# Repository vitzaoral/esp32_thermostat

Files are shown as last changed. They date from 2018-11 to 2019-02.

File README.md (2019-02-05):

# ESP32 thermostat witch touch LCD

WiFi thermostat based on the ESP32 (Espressif WROOM-32 Developer Kit), using several SHT3X(SHT31-D) temperature/humidity sensor and ILI 9341 TFT LCD Touch display. Data are sent to the Blynk server. Thermostat can be controlled by the Blynk application from iPhone or directly by touch on the LCD. Project is free to use, coded in C++, created in Visual Code with [PlatfomIO IDE](http://docs.platformio.org/en/latest/ide/vscode.html).

> To build a project, you need to download all the necessary libraries and create the *settings.cpp* file in the src folder with specific settings:
```c++
// address 1 - enable/disable heating
#define EEPROM_ENABLED_DISABLED_HEATING_ADDRESS 1
// address 2 - target temperature
#define EEPROM_TARGET_HEATING_TEMPERATURE_ADDRESS 2
// address 3 - target temperature was set from display
#define EEPROM_TARGET_HEATING_TEMPERATURE_DISPLAY_SET_ADDRESS 3
// address 4 - heating enabled/disabled was set from display
#define EEPROM_ENABLED_DISABLED_HEATING_DISPLAY_SET_ADDRESS 4

#define MAX_TEMPERATURE_FROM_DISPLAY 25
#define MIN_TEMPERATURE_FROM_DISPLAY 10

// Thermostat project settings
struct Settings
{
    const char *ssid = "WIFI ssid";
    const char *password = "WIFI password";
    const char *blynkAuth = "blynkAuthDevice1";
    const char *blynkAuthOutdoor = "blynkAuthDevice2";
    const char *blynkAuthBedroom = "blynkAuthDevice3";
    const char *blynkAuthPantry = "blynkAuthDevice4";
    const char *hostNameOTA = "OTA host name";
    const char *passwordOTA = "OTA password";
    const char *version = "0.1.0";
};
```

### LCD Touch panel library & wiring:
I'm using awasome [TFT_eSPI](https://github.com/Bodmer/TFT_eSPI) library from Bodmer. You must update *User_Setup.h* file to set display type and pins. There is ESP32 section, my setup for this section is following:

```c++
// ###### EDIT THE PIN NUMBERS IN THE LINES FOLLOWING TO SUIT YOUR ESP32 SETUP   ######

// For ESP32 Dev board (only tested with ILI9341 display)
// The hardware SPI can be mapped to any pins
#define TFT_MISO 19
#define TFT_MOSI 23
#define TFT_SCLK 18
#define TFT_CS   15  // Chip select control pin
#define TFT_DC    2  // Data Command control pin
#define TFT_RST  -1  // Set TFT_RST to -1 if display RESET is connected to ESP32 board RST
#define TOUCH_CS  4  // Chip select pin (T_CS) of touch screen
```

For wires connection between the display and the ESP32 look to the schema..

### 5V relay vs 3.3V ESP32 pins
When you have 5V relay, there is a need to think about 3.3V ESP32 pins. You can't just connect ESP32 pin to source pin of the relay, it would not work. One way is insert MOSFET between ESP32 pin and source pin of the relay. Other solution is just use the 3.3V relay, or solid state relay. More information is [here](https://electronics.stackexchange.com/a/213058).

### Currents list:
* [ESP32](https://www.aliexpress.com/item/ESP-32-ESP-32S-Development-Board-WiFi-Bluetooth-Ultra-Low-Power-Consumption-Dual-Cores-ESP32-Board/32796032726.html) Espressif WROOM-32 Developer Kit
* [HLK-PM01](https://www.aliexpress.com/item/Free-Shippingn-HLK-PM01-AC-DC-220V-to-5V-mini-power-supply-module-intelligent-household-switch/32319515750.html) 220v to 5v power supply
* [Relay module shield](https://www.aliexpress.com/item/Free-Shipping-1PCS-5V-low-level-trigger-One-1-Channel-Relay-Module-interface-Board-Shield-For/32519570562.html)
* [2.8" SPI TFT LCD Touch Panel](https://www.aliexpress.com/item/1pcs-J34-F85-240x320-2-8-SPI-TFT-LCD-Touch-Panel-Serial-Port-Module-with-PCB/32795636902.html)
* [SHT3X (SHT-31D)](https://www.aliexpress.com/item/Free-shipping-SHT31-Temperature-SHT31-D-Humidity-Sensor-module-Breakout-Weather-for-Arduino/32706618932.html) temperature and humidity sensor
* Button, Mosfet

### Schema:
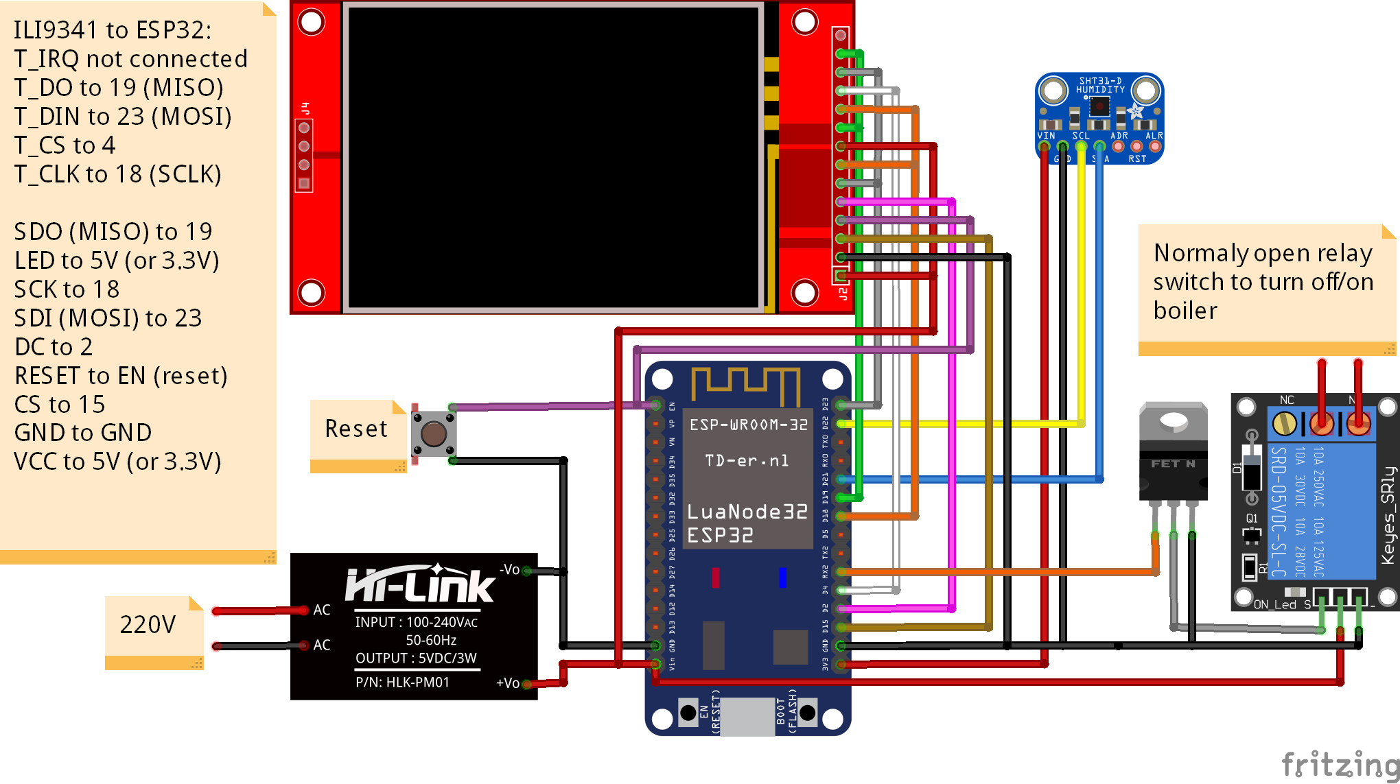
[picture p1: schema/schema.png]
Schema


### Finished project:
How the finished project works is shown in this [YouTube video](https://youtu.be/eb8HEu9pyTQ).

YouTube video here (https://youtu.be/eb8HEu9pyTQ "ESP32 thermostat - Click to Watch!")

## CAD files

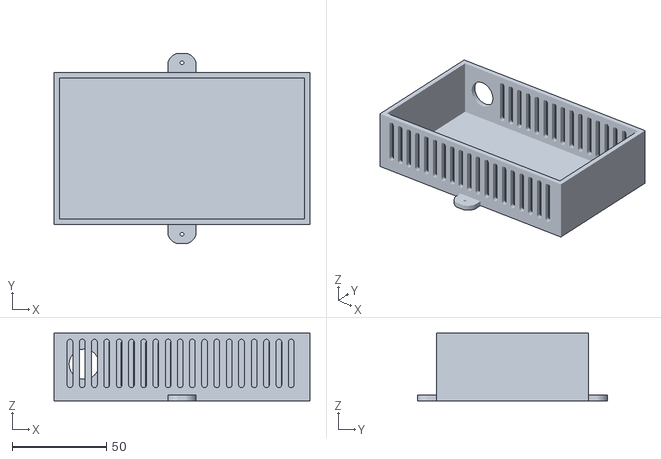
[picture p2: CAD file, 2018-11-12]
3d_print/box.stl
136.0 x 101.0 x 36.0

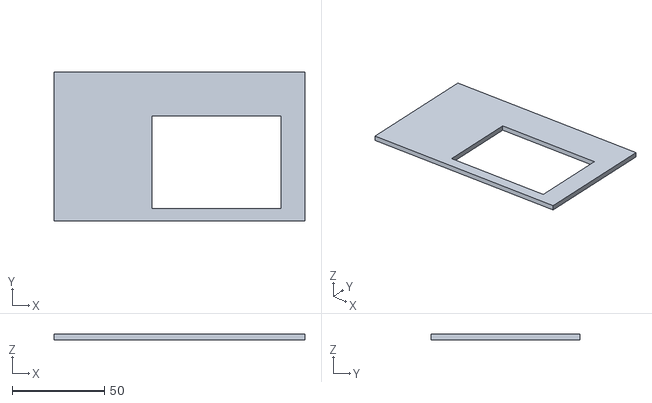
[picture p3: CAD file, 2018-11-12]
3d_print/front.stl
136.0 x 81.0 x 3.00

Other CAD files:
3d_print/box.skp
3d_print/front.skp

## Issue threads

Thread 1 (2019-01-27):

Question: Powering the Wifi Thermostat

kunalshetye, 2019-01-27:
Hi, sorry for the silly question but how is the wifi thermostat powered?

Does the thermostat siphon off power from the 220v (old thermostat) or is it externally powered?

vitzaoral, 2019-02-04:
Hi, sorry for late answer. Yes, exactly as you write, project is powered by the old 220V thermostat. I am using [this 220V to 5V module](https://www.aliexpress.com/item/Hi-Link-ac-dc-power-module-5v-3w-220v-isolated-ac-dc-converter/32360232521.html). So there are four cables between old and new thermostat. Two for power supply (220V) and two for relay module (with switch on and off heating).

vitzaoral, 2019-02-05:
Hello, I [updated wiring diagram](https://github.com/vitzaoral/esp32_thermostat/blob/master/schema/schema.png). It's no big deal, just connect 220V to HiLink module which converts 220V to 5V, or you can go safer way and use some USB charger and connect 5V directly to ESP32 module. Than connect boiler wires to turn on/off heating to relay switch module (to Normally open connector).

Closed 2019-02-12.

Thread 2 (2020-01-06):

error: redefinition of 'struct Settings'

konchris, 2020-01-06:
I get the above error when trying to build the project. I'm not quite sure how to solve the problem.

I've pasted the terminal output below:

> Executing task: platformio run <

Processing esp32dev (platform: espressif32; board: esp32dev; framework: arduino)
--------------------------------------------------------------------------------------------------------------------------------------------------------------------------------------------
Verbose mode can be enabled via `-v, --verbose` option
CONFIGURATION: https://docs.platformio.org/page/boards/espressif32/esp32dev.html
PLATFORM: Espressif 32 1.11.1 > Espressif ESP32 Dev Module
HARDWARE: ESP32 240MHz, 320KB RAM, 4MB Flash
DEBUG: Current (esp-prog) External (esp-prog, iot-bus-jtag, jlink, minimodule, olimex-arm-usb-ocd, olimex-arm-usb-ocd-h, olimex-arm-usb-tiny-h, olimex-jtag-tiny, tumpa)
PACKAGES: toolchain-xtensa32 2.50200.80 (5.2.0), framework-arduinoespressif32 2.10004.191002 (1.0.4), tool-esptoolpy 1.20600.0 (2.6.0)
LDF: Library Dependency Finder -> http://bit.ly/configure-pio-ldf
LDF Modes: Finder ~ chain, Compatibility ~ soft
Found 35 compatible libraries
Scanning dependencies...
Dependency Graph
|-- <Ticker> 3.1.5
|-- <MeteoData>
|   |-- <Adafruit SHT31 Library> 1.1.6
|   |   |-- <Wire> 1.0.1
|-- <InternetConnection>
|   |-- <ArduinoOTA> 1.0
|   |   |-- <ESPmDNS> 1.0
|   |   |   |-- <WiFi> 1.0
|   |   |-- <Update> 1.0
|   |   |-- <WiFi> 1.0
|   |-- <MeteoData>
|   |   |-- <Adafruit SHT31 Library> 1.1.6
|   |   |   |-- <Wire> 1.0.1
|   |-- <WiFi> 1.0
|   |-- <Display>
|   |   |-- <WiFi> 1.0
|   |   |-- <MeteoData>
|   |   |   |-- <Adafruit SHT31 Library> 1.1.6
|   |   |   |   |-- <Wire> 1.0.1
|   |   |-- <SPI> 1.0
|   |   |-- <TFT_eSPI> 1.4.21
|   |   |   |-- <FS> 1.0
|   |   |   |-- <SPI> 1.0
|   |   |   |-- <SPIFFS> 1.0
|   |   |   |   |-- <FS> 1.0
|   |   |-- <EEPROM> 1.0.3
|   |   |-- <FS> 1.0
|   |   |-- <JPEGDecoder> 1.8.0
|   |   |   |-- <SD(esp32)> 1.0.5
|   |   |   |   |-- <FS> 1.0
|   |   |   |   |-- <SPI> 1.0
|   |   |   |-- <FS> 1.0
|   |   |   |-- <SPIFFS> 1.0
|   |   |   |   |-- <FS> 1.0
|   |-- <Blynk> 0.6.1
|   |   |-- <WiFi> 1.0
|   |   |-- <SD(esp32)> 1.0.5
|   |   |   |-- <FS> 1.0
|   |   |   |-- <SPI> 1.0
|   |   |-- <WiFiClientSecure> 1.0
|   |   |   |-- <WiFi> 1.0
|   |-- <EEPROM> 1.0.3
|   |-- <Thermostat>
|   |   |-- <Display>
|   |   |   |-- <WiFi> 1.0
|   |   |   |-- <MeteoData>
|   |   |   |   |-- <Adafruit SHT31 Library> 1.1.6
|   |   |   |   |   |-- <Wire> 1.0.1
|   |   |   |-- <SPI> 1.0
|   |   |   |-- <TFT_eSPI> 1.4.21
|   |   |   |   |-- <FS> 1.0
|   |   |   |   |-- <SPI> 1.0
|   |   |   |   |-- <SPIFFS> 1.0
|   |   |   |   |   |-- <FS> 1.0
|   |   |   |-- <EEPROM> 1.0.3
|   |   |   |-- <FS> 1.0
|   |   |   |-- <JPEGDecoder> 1.8.0
|   |   |   |   |-- <SD(esp32)> 1.0.5
|   |   |   |   |   |-- <FS> 1.0
|   |   |   |   |   |-- <SPI> 1.0
|   |   |   |   |-- <FS> 1.0
|   |   |   |   |-- <SPIFFS> 1.0
|   |   |   |   |   |-- <FS> 1.0
|   |   |-- <MeteoData>
|   |   |   |-- <Adafruit SHT31 Library> 1.1.6
|   |   |   |   |-- <Wire> 1.0.1
|   |   |-- <EEPROM> 1.0.3
|   |-- <HTTPClient> 1.2
|   |   |-- <WiFi> 1.0
|   |   |-- <WiFiClientSecure> 1.0
|   |   |   |-- <WiFi> 1.0
|-- <EEPROM> 1.0.3
|-- <Thermostat>
|   |-- <Display>
|   |   |-- <WiFi> 1.0
|   |   |-- <MeteoData>
|   |   |   |-- <Adafruit SHT31 Library> 1.1.6
|   |   |   |   |-- <Wire> 1.0.1
|   |   |-- <SPI> 1.0
|   |   |-- <TFT_eSPI> 1.4.21
|   |   |   |-- <FS> 1.0
|   |   |   |-- <SPI> 1.0
|   |   |   |-- <SPIFFS> 1.0
|   |   |   |   |-- <FS> 1.0
|   |   |-- <EEPROM> 1.0.3
|   |   |-- <FS> 1.0
|   |   |-- <JPEGDecoder> 1.8.0
|   |   |   |-- <SD(esp32)> 1.0.5
|   |   |   |   |-- <FS> 1.0
|   |   |   |   |-- <SPI> 1.0
|   |   |   |-- <FS> 1.0
|   |   |   |-- <SPIFFS> 1.0
|   |   |   |   |-- <FS> 1.0
|   |-- <MeteoData>
|   |   |-- <Adafruit SHT31 Library> 1.1.6
|   |   |   |-- <Wire> 1.0.1
|   |-- <EEPROM> 1.0.3
|-- <Display>
|   |-- <WiFi> 1.0
|   |-- <MeteoData>
|   |   |-- <Adafruit SHT31 Library> 1.1.6
|   |   |   |-- <Wire> 1.0.1
|   |-- <SPI> 1.0
|   |-- <TFT_eSPI> 1.4.21
|   |   |-- <FS> 1.0
|   |   |-- <SPI> 1.0
|   |   |-- <SPIFFS> 1.0
|   |   |   |-- <FS> 1.0
|   |-- <EEPROM> 1.0.3
|   |-- <FS> 1.0
|   |-- <JPEGDecoder> 1.8.0
|   |   |-- <SD(esp32)> 1.0.5
|   |   |   |-- <FS> 1.0
|   |   |   |-- <SPI> 1.0
|   |   |-- <FS> 1.0
|   |   |-- <SPIFFS> 1.0
|   |   |   |-- <FS> 1.0
Building in release mode
Compiling .pio/build/esp32dev/src/main.cpp.o
Compiling .pio/build/esp32dev/src/settings.cpp.o
In file included from lib/Display/Display.h:4:0,
                 from lib/InternetConnection/InternetConnection.h:10,
                 from src/main.cpp:2:
lib/Display/../../src/settings.cpp:14:8: error: redefinition of 'struct Settings'
 struct Settings
        ^
In file included from lib/InternetConnection/InternetConnection.h:4:0,
                 from src/main.cpp:2:
lib/InternetConnection/../../src/settings.cpp:14:8: error: previous definition of 'struct Settings'
 struct Settings
        ^
In file included from lib/Thermostat/Thermostat.h:4:0,
                 from lib/InternetConnection/InternetConnection.h:11,
                 from src/main.cpp:2:
lib/Thermostat/../../src/settings.cpp:14:8: error: redefinition of 'struct Settings'
 struct Settings
        ^
In file included from lib/InternetConnection/InternetConnection.h:4:0,
                 from src/main.cpp:2:
lib/InternetConnection/../../src/settings.cpp:14:8: error: previous definition of 'struct Settings'
 struct Settings
        ^
Compiling .pio/build/esp32dev/libaf0/Display/Display.cpp.o
Compiling .pio/build/esp32dev/lib7eb/Thermostat/Thermostat.cpp.o
Compiling .pio/build/esp32dev/libece/InternetConnection/InternetConnection.cpp.o
In file included from lib/Display/Display.h:4:0,
                 from lib/Thermostat/Thermostat.h:8,
                 from lib/Thermostat/Thermostat.cpp:1:
lib/Display/../../src/settings.cpp:14:8: error: redefinition of 'struct Settings'
 struct Settings
        ^
In file included from lib/Thermostat/Thermostat.h:4:0,
                 from lib/Thermostat/Thermostat.cpp:1:
lib/Thermostat/../../src/settings.cpp:14:8: error: previous definition of 'struct Settings'
 struct Settings
        ^
In file included from /Users/chris/.platformio/packages/framework-arduinoespressif32/tools/sdk/include/lwip/lwip/ip_addr.h:41:0,
                 from /Users/chris/.platformio/packages/framework-arduinoespressif32/tools/sdk/include/tcpip_adapter/tcpip_adapter.h:45,
                 from /Users/chris/.platformio/packages/framework-arduinoespressif32/tools/sdk/include/esp32/esp_event_legacy.h:23,
                 from /Users/chris/.platformio/packages/framework-arduinoespressif32/tools/sdk/include/esp_event/esp_event.h:26,
                 from /Users/chris/.platformio/packages/framework-arduinoespressif32/tools/sdk/include/esp32/esp_event_loop.h:22,
                 from /Users/chris/.platformio/packages/framework-arduinoespressif32/libraries/WiFi/src/WiFiGeneric.h:27,
                 from /Users/chris/.platformio/packages/framework-arduinoespressif32/libraries/WiFi/src/WiFiSTA.h:28,
                 from /Users/chris/.platformio/packages/framework-arduinoespressif32/libraries/WiFi/src/WiFi.h:32,
                 from /Users/chris/.platformio/lib/Blynk_ID415/src/BlynkSimpleEsp32.h:23,
                 from lib/InternetConnection/InternetConnection.cpp:1:
/Users/chris/.platformio/packages/framework-arduinoespressif32/tools/sdk/include/lwip/lwip/def.h:108:0: warning: "htons" redefined
 #define htons(x) lwip_htons(x)
 ^
In file included from /Users/chris/.platformio/lib/Blynk_ID415/src/Blynk/BlynkApi.h:19:0,
                 from /Users/chris/.platformio/lib/Blynk_ID415/src/BlynkApiArduino.h:14,
                 from /Users/chris/.platformio/lib/Blynk_ID415/src/BlynkSimpleEsp32.h:20,
                 from lib/InternetConnection/InternetConnection.cpp:1:
/Users/chris/.platformio/lib/Blynk_ID415/src/Blynk/BlynkProtocolDefs.h:78:0: note: this is the location of the previous definition
         #define htons(x) ( ((x)<<8) | (((x)>>8)&0xFF) )
 ^
In file included from /Users/chris/.platformio/packages/framework-arduinoespressif32/tools/sdk/include/lwip/lwip/ip_addr.h:41:0,
                 from /Users/chris/.platformio/packages/framework-arduinoespressif32/tools/sdk/include/tcpip_adapter/tcpip_adapter.h:45,
                 from /Users/chris/.platformio/packages/framework-arduinoespressif32/tools/sdk/include/esp32/esp_event_legacy.h:23,
                 from /Users/chris/.platformio/packages/framework-arduinoespressif32/tools/sdk/include/esp_event/esp_event.h:26,
                 from /Users/chris/.platformio/packages/framework-arduinoespressif32/tools/sdk/include/esp32/esp_event_loop.h:22,
                 from /Users/chris/.platformio/packages/framework-arduinoespressif32/libraries/WiFi/src/WiFiGeneric.h:27,
                 from /Users/chris/.platformio/packages/framework-arduinoespressif32/libraries/WiFi/src/WiFiSTA.h:28,
                 from /Users/chris/.platformio/packages/framework-arduinoespressif32/libraries/WiFi/src/WiFi.h:32,
                 from /Users/chris/.platformio/lib/Blynk_ID415/src/BlynkSimpleEsp32.h:23,
                 from lib/InternetConnection/InternetConnection.cpp:1:
/Users/chris/.platformio/packages/framework-arduinoespressif32/tools/sdk/include/lwip/lwip/def.h:109:0: warning: "ntohs" redefined
 #define ntohs(x) lwip_ntohs(x)
 ^
In file included from /Users/chris/.platformio/lib/Blynk_ID415/src/Blynk/BlynkApi.h:19:0,
                 from /Users/chris/.platformio/lib/Blynk_ID415/src/BlynkApiArduino.h:14,
                 from /Users/chris/.platformio/lib/Blynk_ID415/src/BlynkSimpleEsp32.h:20,
                 from lib/InternetConnection/InternetConnection.cpp:1:
/Users/chris/.platformio/lib/Blynk_ID415/src/Blynk/BlynkProtocolDefs.h:83:0: note: this is the location of the previous definition
         #define ntohs(x) htons(x)
 ^
In file included from /Users/chris/.platformio/packages/framework-arduinoespressif32/tools/sdk/include/lwip/lwip/ip_addr.h:41:0,
                 from /Users/chris/.platformio/packages/framework-arduinoespressif32/tools/sdk/include/tcpip_adapter/tcpip_adapter.h:45,
                 from /Users/chris/.platformio/packages/framework-arduinoespressif32/tools/sdk/include/esp32/esp_event_legacy.h:23,
                 from /Users/chris/.platformio/packages/framework-arduinoespressif32/tools/sdk/include/esp_event/esp_event.h:26,
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
vitzaoral, 2020-01-14:
Hello, I don't know, what can cause a problem, it seems to some redelceration of _Settings_ struct as error says. Are you sure that you have created _Settings.cpp_ file on the same place where _Main.cpp_ is located (_src_ folder)? Then _Settings.cpp_ file should seems like this:

`
#ifndef __Settings_H
#define __Settings_H

// address 1 - enable/disable heating
#define EEPROM_ENABLED_DISABLED_HEATING_ADDRESS 1
// address 2 - target temperature
#define EEPROM_TARGET_HEATING_TEMPERATURE_ADDRESS 2
// address 3 - target temperature was set from display
#define EEPROM_TARGET_HEATING_TEMPERATURE_DISPLAY_SET_ADDRESS 3
// address 4 - heating enabled/disabled was set from display
#define EEPROM_ENABLED_DISABLED_HEATING_DISPLAY_SET_ADDRESS 4

#define MAX_TEMPERATURE_FROM_DISPLAY 25
#define MIN_TEMPERATURE_FROM_DISPLAY 10

struct Settings
{
    const char *ssid = "xxx";
    const char *password = "xxx";
    const char *blynkAuth = "xxx";        // Thermostat
    const char *blynkAuthOutdoor = "xxx"; // Watering system
    const char *blynkAuthBedroom = "xxx"; // Bedroom sensor
    const char *blynkAuthPantry = "xxx";  // Pantry sensor
    const char *hostNameOTA = "Thermostat";
    const char *passwordOTA = "pwdXXX";
    const char *version = "0.1.0";
};

#endif
`

vitzaoral, 2020-02-02:
Closed due to lack of interest.

Closed 2020-02-02.

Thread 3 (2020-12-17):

error: undefined reference to `TFT_eSPI::getTouch(unsigned short*, unsigned short*, unsigned short)'

lex007112, 2020-12-17:
I can not compile the firmware

> > Executing task in folder esp32_thermostat-master: C:\Users\le_x_\.platformio\penv\Scripts\pio.exe run <

Processing esp32dev (platform: espressif32; board: esp32dev; framework: arduino)
---------------------------------------------------------------------------------------------------------------------------------------------------------------------------------------------------------------------------------
Verbose mode can be enabled via `-v, --verbose` option
CONFIGURATION: https://docs.platformio.org/page/boards/espressif32/esp32dev.html
PLATFORM: Espressif 32 (2.0.0) > Espressif ESP32 Dev Module
HARDWARE: ESP32 240MHz, 320KB RAM, 4MB Flash
DEBUG: Current (esp-prog) External (esp-prog, iot-bus-jtag, jlink, minimodule, olimex-arm-usb-ocd, olimex-arm-usb-ocd-h, olimex-arm-usb-tiny-h, olimex-jtag-tiny, tumpa)
PACKAGES:
 - framework-arduinoespressif32 3.10004.201016 (1.0.4)
 - tool-esptoolpy 1.20600.0 (2.6.0)
 - toolchain-xtensa32 2.50200.80 (5.2.0)
LDF: Library Dependency Finder -> http://bit.ly/configure-pio-ldf
LDF Modes: Finder ~ chain, Compatibility ~ soft
Found 41 compatible libraries
Scanning dependencies...
Dependency Graph
|-- <Adafruit SHT31 Library> 2.0.0
|   |-- <Adafruit BusIO> 1.7.1
|   |   |-- <Wire> 1.0.1
|   |   |-- <SPI> 1.0
|   |-- <Wire> 1.0.1
|-- <JPEGDecoder> 1.8.1
|   |-- <FS> 1.0
|   |-- <SPIFFS> 1.0
|   |   |-- <FS> 1.0
|   |-- <SD(esp32)> 1.0.5
|   |   |-- <FS> 1.0
|   |   |-- <SPI> 1.0
|-- <Ticker> 3.2.0
|-- <Blynk> 0.6.7
|   |-- <WiFi> 1.0
|   |-- <WiFiClientSecure> 1.0
|   |   |-- <WiFi> 1.0
|   |-- <SD(esp32)> 1.0.5
|   |   |-- <FS> 1.0
|   |   |-- <SPI> 1.0
|-- <TFT_eSPI> 2.3.52
|   |-- <SPIFFS> 1.0
|   |   |-- <FS> 1.0
|   |-- <FS> 1.0
|   |-- <SPI> 1.0
|-- <ArduinoJson> 6.17.2
|-- <Adafruit GFX Library> 1.10.4
|   |-- <Adafruit BusIO> 1.7.1
|   |   |-- <Wire> 1.0.1
|   |   |-- <SPI> 1.0
|   |-- <Wire> 1.0.1
|   |-- <SPI> 1.0
|-- <Adafruit ILI9341> 1.5.6
|   |-- <Adafruit GFX Library> 1.10.4
|   |   |-- <Adafruit BusIO> 1.7.1
|   |   |   |-- <Wire> 1.0.1
|   |   |   |-- <SPI> 1.0
|   |   |-- <Wire> 1.0.1
|   |   |-- <SPI> 1.0
|   |-- <SPI> 1.0
|-- <Display>
|   |-- <EEPROM> 1.0.3
|   |-- <FS> 1.0
|   |-- <TFT_eSPI> 2.3.52
|   |   |-- <SPIFFS> 1.0
|   |   |   |-- <FS> 1.0
|   |   |-- <FS> 1.0
|   |   |-- <SPI> 1.0
|   |-- <JPEGDecoder> 1.8.1
|   |   |-- <FS> 1.0
|   |   |-- <SPIFFS> 1.0
|   |   |   |-- <FS> 1.0
|   |   |-- <SD(esp32)> 1.0.5
|   |   |   |-- <FS> 1.0
|   |   |   |-- <SPI> 1.0
|   |-- <MeteoData>
|   |   |-- <Adafruit SHT31 Library> 2.0.0
|   |   |   |-- <Adafruit BusIO> 1.7.1
|   |   |   |   |-- <Wire> 1.0.1
|   |   |   |   |-- <SPI> 1.0
|   |   |   |-- <Wire> 1.0.1
|   |-- <SPI> 1.0
|   |-- <WiFi> 1.0
|-- <EEPROM> 1.0.3
|-- <InternetConnection>
|   |-- <ArduinoOTA> 1.0
|   |   |-- <Update> 1.0
|   |   |-- <WiFi> 1.0
|   |   |-- <ESPmDNS> 1.0
|   |   |   |-- <WiFi> 1.0
|   |-- <Display>
|   |   |-- <EEPROM> 1.0.3
|   |   |-- <FS> 1.0
|   |   |-- <TFT_eSPI> 2.3.52
|   |   |   |-- <SPIFFS> 1.0
|   |   |   |   |-- <FS> 1.0
|   |   |   |-- <FS> 1.0
|   |   |   |-- <SPI> 1.0
|   |   |-- <JPEGDecoder> 1.8.1
|   |   |   |-- <FS> 1.0
|   |   |   |-- <SPIFFS> 1.0
|   |   |   |   |-- <FS> 1.0
|   |   |   |-- <SD(esp32)> 1.0.5
|   |   |   |   |-- <FS> 1.0
|   |   |   |   |-- <SPI> 1.0
|   |   |-- <MeteoData>
|   |   |   |-- <Adafruit SHT31 Library> 2.0.0
|   |   |   |   |-- <Adafruit BusIO> 1.7.1
|   |   |   |   |   |-- <Wire> 1.0.1
|   |   |   |   |   |-- <SPI> 1.0
|   |   |   |   |-- <Wire> 1.0.1
|   |   |-- <SPI> 1.0
|   |   |-- <WiFi> 1.0
|   |-- <EEPROM> 1.0.3
|   |-- <HTTPClient> 1.2
|   |   |-- <WiFi> 1.0
|   |   |-- <WiFiClientSecure> 1.0
|   |   |   |-- <WiFi> 1.0
|   |-- <MeteoData>
|   |   |-- <Adafruit SHT31 Library> 2.0.0
|   |   |   |-- <Adafruit BusIO> 1.7.1
|   |   |   |   |-- <Wire> 1.0.1
|   |   |   |   |-- <SPI> 1.0
|   |   |   |-- <Wire> 1.0.1
|   |-- <Thermostat>
|   |   |-- <Display>
|   |   |   |-- <EEPROM> 1.0.3
|   |   |   |-- <FS> 1.0
|   |   |   |-- <TFT_eSPI> 2.3.52
|   |   |   |   |-- <SPIFFS> 1.0
|   |   |   |   |   |-- <FS> 1.0
|   |   |   |   |-- <FS> 1.0
|   |   |   |   |-- <SPI> 1.0
|   |   |   |-- <JPEGDecoder> 1.8.1
|   |   |   |   |-- <FS> 1.0
|   |   |   |   |-- <SPIFFS> 1.0
|   |   |   |   |   |-- <FS> 1.0
|   |   |   |   |-- <SD(esp32)> 1.0.5
|   |   |   |   |   |-- <FS> 1.0
|   |   |   |   |   |-- <SPI> 1.0
|   |   |   |-- <MeteoData>
|   |   |   |   |-- <Adafruit SHT31 Library> 2.0.0
|   |   |   |   |   |-- <Adafruit BusIO> 1.7.1
|   |   |   |   |   |   |-- <Wire> 1.0.1
|   |   |   |   |   |   |-- <SPI> 1.0
|   |   |   |   |   |-- <Wire> 1.0.1
|   |   |   |-- <SPI> 1.0
|   |   |   |-- <WiFi> 1.0
|   |   |-- <EEPROM> 1.0.3
|   |   |-- <MeteoData>
|   |   |   |-- <Adafruit SHT31 Library> 2.0.0
|   |   |   |   |-- <Adafruit BusIO> 1.7.1
|   |   |   |   |   |-- <Wire> 1.0.1
|   |   |   |   |   |-- <SPI> 1.0
|   |   |   |   |-- <Wire> 1.0.1
|   |-- <WiFi> 1.0
|   |-- <Blynk> 0.6.7
|   |   |-- <WiFi> 1.0
|   |   |-- <WiFiClientSecure> 1.0
|   |   |   |-- <WiFi> 1.0
|   |   |-- <SD(esp32)> 1.0.5
|   |   |   |-- <FS> 1.0
|   |   |   |-- <SPI> 1.0
|-- <MeteoData>
|   |-- <Adafruit SHT31 Library> 2.0.0
|   |   |-- <Adafruit BusIO> 1.7.1
|   |   |   |-- <Wire> 1.0.1
|   |   |   |-- <SPI> 1.0
|   |   |-- <Wire> 1.0.1
|-- <Thermostat>
|   |-- <Display>
|   |   |-- <EEPROM> 1.0.3
|   |   |-- <FS> 1.0
|   |   |-- <TFT_eSPI> 2.3.52
|   |   |   |-- <SPIFFS> 1.0
|   |   |   |   |-- <FS> 1.0
|   |   |   |-- <FS> 1.0
|   |   |   |-- <SPI> 1.0
|   |   |-- <JPEGDecoder> 1.8.1
|   |   |   |-- <FS> 1.0
|   |   |   |-- <SPIFFS> 1.0
|   |   |   |   |-- <FS> 1.0
|   |   |   |-- <SD(esp32)> 1.0.5
|   |   |   |   |-- <FS> 1.0
|   |   |   |   |-- <SPI> 1.0
|   |   |-- <MeteoData>
|   |   |   |-- <Adafruit SHT31 Library> 2.0.0
|   |   |   |   |-- <Adafruit BusIO> 1.7.1
|   |   |   |   |   |-- <Wire> 1.0.1
|   |   |   |   |   |-- <SPI> 1.0
|   |   |   |   |-- <Wire> 1.0.1
|   |   |-- <SPI> 1.0
|   |   |-- <WiFi> 1.0
|   |-- <EEPROM> 1.0.3
|   |-- <MeteoData>
|   |   |-- <Adafruit SHT31 Library> 2.0.0
|   |   |   |-- <Adafruit BusIO> 1.7.1
|   |   |   |   |-- <Wire> 1.0.1
|   |   |   |   |-- <SPI> 1.0
|   |   |   |-- <Wire> 1.0.1
Building in release mode
Compiling .pio\build\esp32dev\src\main.cpp.o
Compiling .pio\build\esp32dev\liba0a\Display\Display.cpp.o
Compiling .pio\build\esp32dev\liba0a\Display\GfxUi.cpp.o
Compiling .pio\build\esp32dev\liba0a\Display\JpegUtils.cpp.o
Compiling .pio\build\esp32dev\lib5b4\Thermostat\Thermostat.cpp.o
Compiling .pio\build\esp32dev\libf34\InternetConnection\InternetConnection.cpp.o
Archiving .pio\build\esp32dev\liba0a\libDisplay.a
Archiving .pio\build\esp32dev\lib5b4\libThermostat.a
Archiving .pio\build\esp32dev\libf34\libInternetConnection.a
Linking .pio\build\esp32dev\firmware.elf
.pio\build\esp32dev\liba0a\libDisplay.a(Display.cpp.o):(.literal._ZN7Display19checkDisplayClickedEv+0xc): undefined reference to `TFT_eSPI::getTouch(unsigned short*, unsigned short*, unsigned short)'
.pio\build\esp32dev\liba0a\libDisplay.a(Display.cpp.o): In function `Display::checkDisplayClicked()':
E:\firmware_vscode\esp32_thermostat-master/lib\Display/Display.cpp:287: undefined reference to `TFT_eSPI::getTouch(unsigned short*, unsigned short*, unsigned short)'
collect2.exe: error: ld returned 1 exit status
*** [.pio\build\esp32dev\firmware.elf] Error 1

lex007112, 2020-12-17:
problem solved by adding library tft_hspi

Closed 2020-12-17.

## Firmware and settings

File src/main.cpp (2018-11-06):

#include <Arduino.h>
#include <InternetConnection.h>
#include <MeteoData.h>
#include <Thermostat.h>
#include <Display.h>
#include <Ticker.h>
#include <EEPROM.h>

InternetConnection connection;

// intervals in miliseconds
const int readMeteoDataInterval = 28523;
const int readOtherSensorsMeteoDataInterval = 65123;
const int sendDataToBlynkInterval = 60321;
const int checkDisplayClickedInterval = 43;
const int checkWasTemperatureDisplaySetInterval = 15321;
const int checkWasHeatingDisplaySetInterval = 15800;

void readMeteoData();
void readOtherSensorsMeteoData();
void sendDataToBlynk();
void controllThermostat();
void checkDisplayClicked();
void checkWasTemperatureDisplaySet();
void checkWasHeatingDisplaySet();

Ticker timerReadMeteoData(readMeteoData, readMeteoDataInterval);
Ticker timerSendDataToBlynk(sendDataToBlynk, sendDataToBlynkInterval);
Ticker timerReadOtherSensorsMeteoData(readOtherSensorsMeteoData, readOtherSensorsMeteoDataInterval);
Ticker timerControllThermostat(controllThermostat, CONTROLL_THERMOSTAT_INTERVAL * 1000);
Ticker timerCheckDisplayClicked(checkDisplayClicked, checkDisplayClickedInterval);
Ticker timerCheckWasTemperatureDisplaySet(checkWasTemperatureDisplaySet, checkWasTemperatureDisplaySetInterval);
Ticker timerCheckWasHeatingDisplaySet(checkWasHeatingDisplaySet, checkWasHeatingDisplaySetInterval);

// Connections to APIs are OK
bool apisAreConnected = false;

void initializeInternetConnection()
{
    if (connection.initialize())
    {
        apisAreConnected = connection.initializeBlynk();
        connection.initializeOTA();
    }
    Display::printWifiStatusAndPrepareTemplate();
}

void readMeteoData()
{
    MeteoData::setData();
    Display::printLocalMeteoData();
}

void readOtherSensorsMeteoData()
{
    connection.setOutdoorMeteoData();
    connection.setBedroomMeteoData();
    connection.setPantryMeteoData();
    Display::printSensorsMeteoData();
}

void checkWasTemperatureDisplaySet()
{
    if (EEPROM.read(EEPROM_TARGET_HEATING_TEMPERATURE_DISPLAY_SET_ADDRESS) == true)
    {
        int targetTemperature = EEPROM.read(EEPROM_TARGET_HEATING_TEMPERATURE_ADDRESS);
        InternetConnection::setTargetTemperatureToBlynk(targetTemperature, true);
        Serial.print("Temperature setted on display to: ");
        Serial.println(targetTemperature);

        EEPROM.write(EEPROM_TARGET_HEATING_TEMPERATURE_DISPLAY_SET_ADDRESS, 0);
        EEPROM.commit();
    }
}

void checkWasHeatingDisplaySet()
{
    if (EEPROM.read(EEPROM_ENABLED_DISABLED_HEATING_DISPLAY_SET_ADDRESS) == true)
    {
        bool enabled = EEPROM.read(EEPROM_ENABLED_DISABLED_HEATING_ADDRESS);
        InternetConnection::setHeatingEnabledDisabledToBlynk(enabled);
        Serial.print("Heating enabled/disabled setted on display to: ");
        Serial.println(enabled);

        EEPROM.write(EEPROM_ENABLED_DISABLED_HEATING_DISPLAY_SET_ADDRESS, 0);
        EEPROM.commit();
    }
}

void controllThermostat()
{
    ThermostatStatus status = Thermostat::controllThermostat();

    InternetConnection::setStatusToBlynk(status.message, status.color);
    InternetConnection::setIsHeatingToBlynk(status.isHeating);
}

void sendDataToBlynk()
{
    if (apisAreConnected)
    {
        bool successBlynk = connection.sendDataToBlynk();

        if (successBlynk)
        {
            Serial.println("Data was sent to Blynk");
        }
        else
        {
            Serial.println("No internet connection, try initialize connection");
            apisAreConnected = false;
            initializeInternetConnection();
        }
    }
    else
    {
        initializeInternetConnection();
    }
}

void checkDisplayClicked()
{
    Display::checkDisplayClicked();
}

void startTimers()
{
    timerReadMeteoData.start();
    timerReadOtherSensorsMeteoData.start();
    timerSendDataToBlynk.start();
    timerControllThermostat.start();
    timerCheckDisplayClicked.start();
    timerCheckWasTemperatureDisplaySet.start();
    timerCheckWasHeatingDisplaySet.start();
}

void updateTimers()
{
    timerReadMeteoData.update();
    timerReadOtherSensorsMeteoData.update();
    timerSendDataToBlynk.update();
    timerControllThermostat.update();
    timerCheckDisplayClicked.update();
    timerCheckWasTemperatureDisplaySet.update();
    timerCheckWasHeatingDisplaySet.update();
}

void setup()
{
    // Initialize 10 addresses:
    // 1. device status (enabled/disabled)
    // 2. required temperature
    // 3. was setted targe temperature from display
    // 4. was setted enabled/disabled heating from display
    EEPROM.begin(10);
    Serial.begin(9600);

    // initialize components
    Display::initialize();
    MeteoData::initialize();
    Thermostat::initialize();

    // try connect to internet
    initializeInternetConnection();

    // start process in timers
    startTimers();
}

void loop()
{
    updateTimers();
    connection.runBlynk();
    connection.handleOTA();
}

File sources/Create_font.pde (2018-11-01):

// This is a Processing sketch, see https://processing.org/ to download the IDE

// Select the character range in the user configure section starting at line 100

/*
Software License Agreement (FreeBSD License)
 
 Copyright (c) 2018 Bodmer (https://github.com/Bodmer)
 
 All rights reserved.
 
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
 1. Redistributions of source code must retain the above copyright notice, this
 list of conditions and the following disclaimer.
 2. Redistributions in binary form must reproduce the above copyright notice,
 this list of conditions and the following disclaimer in the documentation
 and/or other materials provided with the distribution.
 
 THIS SOFTWARE IS PROVIDED BY THE COPYRIGHT HOLDERS AND CONTRIBUTORS "AS IS" AND
 ANY EXPRESS OR IMPLIED WARRANTIES, INCLUDING, BUT NOT LIMITED TO, THE IMPLIED
 WARRANTIES OF MERCHANTABILITY AND FITNESS FOR A PARTICULAR PURPOSE ARE
 DISCLAIMED. IN NO EVENT SHALL THE COPYRIGHT OWNER OR CONTRIBUTORS BE LIABLE FOR
 ANY DIRECT, INDIRECT, INCIDENTAL, SPECIAL, EXEMPLARY, OR CONSEQUENTIAL DAMAGES
 (INCLUDING, BUT NOT LIMITED TO, PROCUREMENT OF SUBSTITUTE GOODS OR SERVICES;
 LOSS OF USE, DATA, OR PROFITS; OR BUSINESS INTERRUPTION) HOWEVER CAUSED AND
 ON ANY THEORY OF LIABILITY, WHETHER IN CONTRACT, STRICT LIABILITY, OR TORT
 (INCLUDING NEGLIGENCE OR OTHERWISE) ARISING IN ANY WAY OUT OF THE USE OF THIS
 SOFTWARE, EVEN IF ADVISED OF THE POSSIBILITY OF SUCH DAMAGE.
 
 The views and conclusions contained in the software and documentation are those
 of the authors and should not be interpreted as representing official policies,
 either expressed or implied, of the FreeBSD Project.
 */

////////////////////////////////////////////////////////////////////////////////////////////////


// This is a processing sketch to create font files for the TFT_eSPI library:

// https://github.com/Bodmer/TFT_eSPI

// Coded by Bodmer January 2018

// See comments below in code for specifying the font parameters
// (point size, unicode blocks to include etc). Ranges of characers or
// specific individual unicodes can be included in the created font file/

// Created fonts are saved in the sketches "FontFiles" folder. Press Ctrl+K to
// see that folder.

// 16 bit unicodes in the range 0x0000 - 0xFFFF are supported.

// The sketch will convert True Type (a .ttf or .otf file) file stored in the
// sketches "Data" folder as well as your computers system fonts.

// To maximise rendering performance only include the characters you will use.
// Characters at the start of the file will render faster than those at the end.

// Once created the files must be loaded into the ESP32 or ESP8266 SPIFFS memory
// using the Arduino IDE plugin detailed here:
// https://github.com/esp8266/arduino-esp8266fs-plugin
// https://github.com/me-no-dev/arduino-esp32fs-plugin

// The sketch list all the available PC fonts to the console, you may need to increase
// console line count (in preferences.txt) to stop some fonts scrolling out of view.
// See link in File>Preferences to locate "preferences.txt" file. You must close
// Processing then edit the file lines. If Processing is not closed first then the
// edits will be overwritten by defaults! Edit "preferences.txt" as follows for
// 1000 lines, then save, then run Processing again:

 /*
   console.length=1000             // Line 4 in file
   console.scrollback.lines=1000   // Line 7 in file
 */

// Useful links:
 /*
 https://en.wikipedia.org/wiki/Unicode_font
 
 https://www.gnu.org/software/freefont/
 https://www.gnu.org/software/freefont/sources/
 https://www.gnu.org/software/freefont/ranges/
 http://savannah.gnu.org/projects/freefont/
 
 http://www.google.com/get/noto/
 https://github.com/Bodmer/TFT_eSPI
 https://github.com/esp8266/arduino-esp8266fs-plugin
 https://github.com/me-no-dev/arduino-esp32fs-plugin
 
 */
////////////////////////////////////////////////////////////////////////////////////////////////

import java.awt.Desktop;

//                       >>>>>>>>>> USER CONFIGURED PARAMETERS START HERE <<<<<<<<<<


// Use font name for ttf files placed in the "Data" folder or the font number seen in IDE Console for system fonts
//                                                  the font numbers are listed when the sketch is run.
//                |         1         2     |       Maximum filename size for SPIFFS is 32 including leading /
//                 1234567890123456789012345        and added point size and .vlw extension, so max is 25
String fontName = "NotoSansThin";  //Manually crop the filename length later after creation if needed

String fontType = ".ttf";            //SPIFFS does not accept underscore in filename!
//String fontType = ".otf";

// Use font number instead of name, -1 means use name above, or a value >=0 means use system font number from list.
int fontNumber = -1; // << Use [Number] in brackets from the fonts listed in console window

// Define the font size in points for the created font file
int  fontSize = 10;

// Font size to use in the Processing sketch display window that pops up (can be different to above)
int displayFontSize = 10;

///////////////////////////////////////////////////////////////////////////////////////////////////////////////////////////
// Next we specify which unicode blocks from the the Basic Multilingual Plane (BMP) are included in the final font file. //
// Note: The ttf/otf font file MAY NOT contain all possible Unicode characters, refer to the fonts online documentation. //
///////////////////////////////////////////////////////////////////////////////////////////////////////////////////////////
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

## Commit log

2018-10-04 Include SHT31 temperature sensor
2018-10-08 Schema and display to ESP32 wiring description
    [schema.fzz]
2018-10-09 Read outdoor temperature/humidity sensor from Blynk
2018-10-09 Refactor of showing outdoor sensor data
2018-10-10 Relay, Blynk relay test
    [schema.fzz]
2018-10-10 Other temperature sensors
2018-10-18 Heating target temperature, showing on display, refactor..
2018-11-03 Next temperature/humidity sensor
2018-11-05 Set temperature over display, synchronize to Blynk
2018-11-06 Heating on/off display click synchronize to Blynk
2018-11-07 Added reset button to schema
    [schema.fzz]
2018-11-12 Box SketchUp
    [box.skp, box.stl, front.skp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]
2019-02-05 Update schema
    [schema.fzz]
